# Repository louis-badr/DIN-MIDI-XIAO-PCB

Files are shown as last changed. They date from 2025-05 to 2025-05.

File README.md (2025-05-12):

# DIN-MIDI-XIAO-PCB

<div>
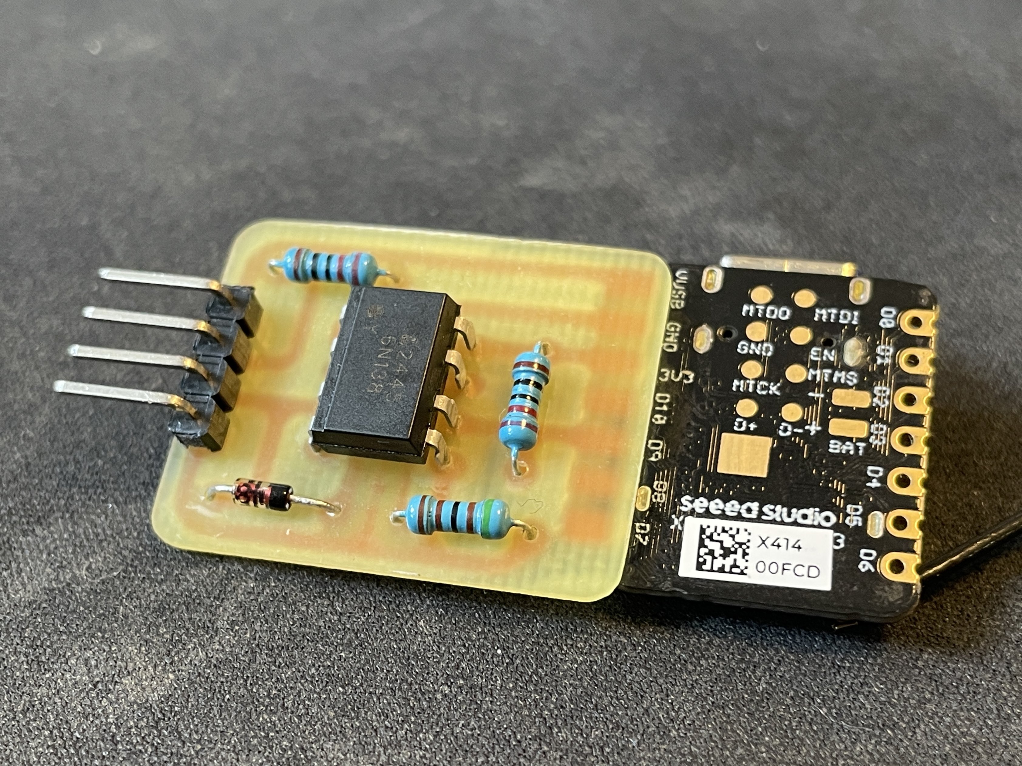
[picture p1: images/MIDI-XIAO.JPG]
    
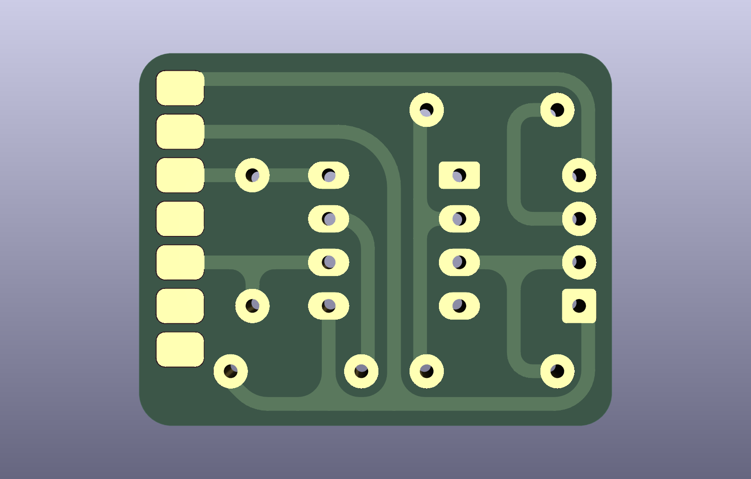
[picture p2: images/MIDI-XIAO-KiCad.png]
    
</div>

DIN MIDI PCB for Seeed Studio XIAO format boards - designed for CNC milling

Pinout:

-   Pin 1 -> GND
-   Pin 2 -> MIDI- / 5
-   Pin 3 -> MIDI+ / 4
-   Pin 4 -> +5V

Pin 1 and 4 are for powering the XIAO board, only connect them when USB is not.

```c++
#include <HardwareSerial.h>
#include <MIDI.h>

#define MIDI_IN 8 // pin 8 for XIAO ESP32S3 - change to your pin

MIDI_CREATE_INSTANCE(HardwareSerial, Serial1, MIDI)

void setup()
{
    Serial.begin(115200); // for debugging
    Serial1.begin(31250, SERIAL_8N1, MIDI_IN, -1); // for MIDI input
    MIDI.begin(MIDI_CHANNEL_OMNI);
}

void loop()
{
    MIDI.read();
}
```

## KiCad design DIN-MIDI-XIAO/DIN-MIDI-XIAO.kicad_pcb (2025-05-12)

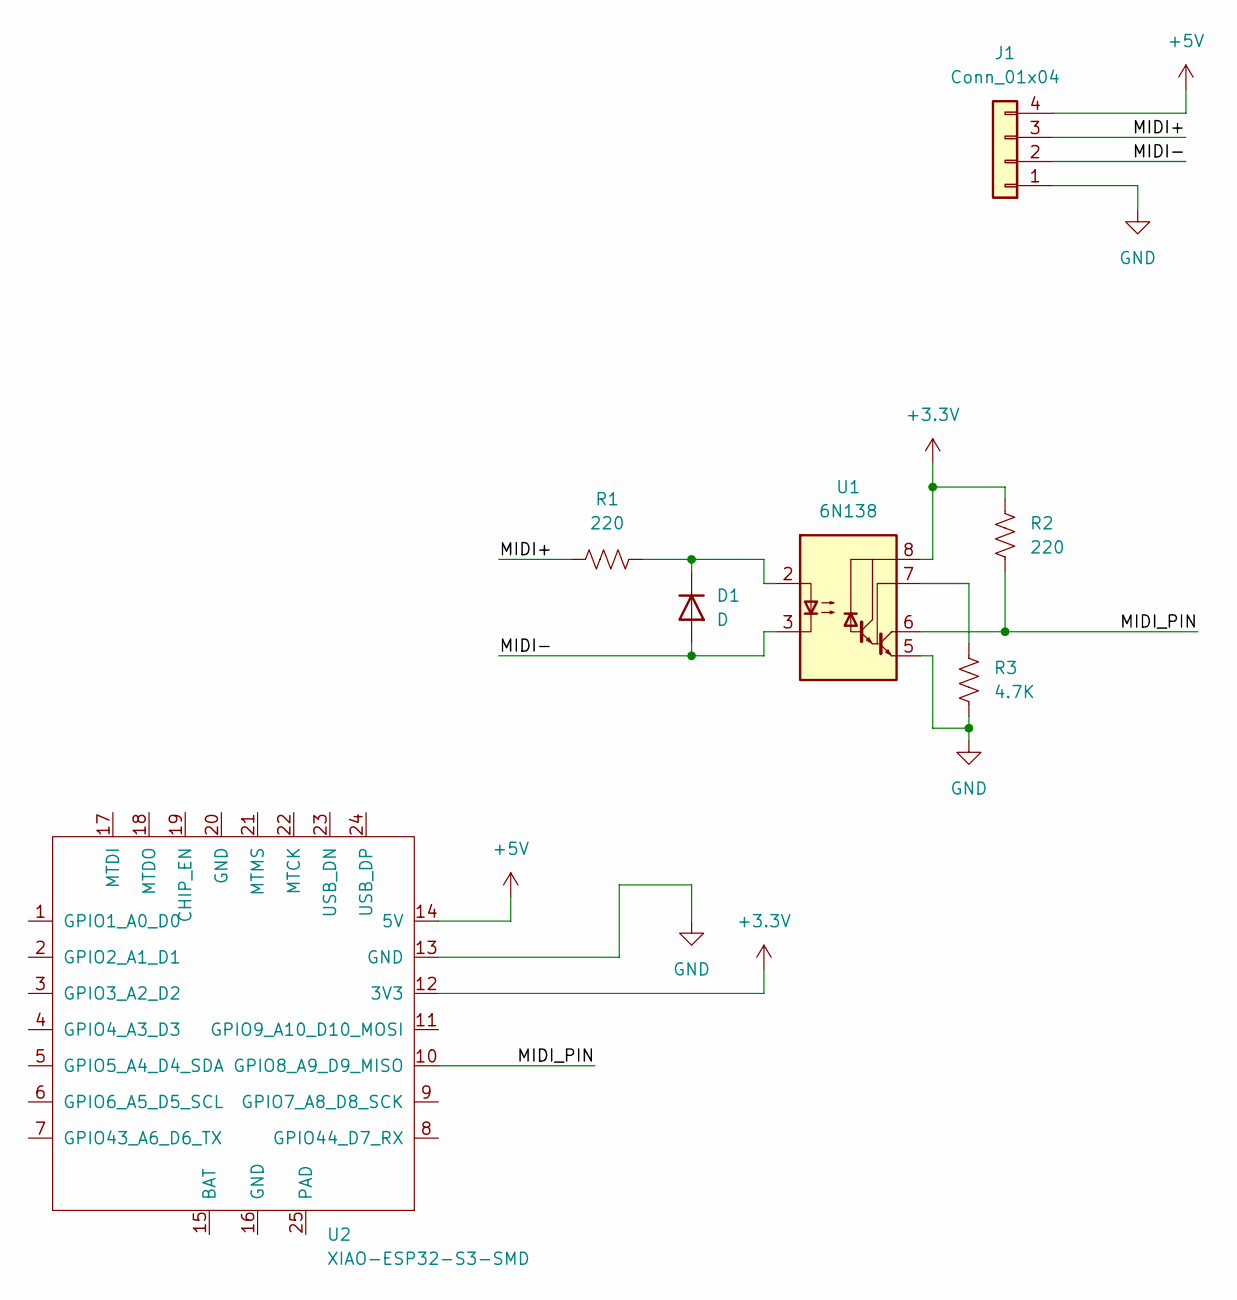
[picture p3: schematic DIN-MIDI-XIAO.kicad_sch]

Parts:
D1: D; R_Axial_DIN0207_L6.3mm_D2.5mm_P7.62mm_Horizontal
J1: Conn_01x04; PinHeader_1x04_P2.54mm_Horizontal
R1, R2: 220; R_Axial_DIN0207_L6.3mm_D2.5mm_P7.62mm_Horizontal
R3: 4.7K; R_Axial_DIN0207_L6.3mm_D2.5mm_P7.62mm_Horizontal
U1: 6N138; DIP-8_W7.62mm_Socket_LongPads
U2: XIAO-ESP32-S3-SMD; XIAO-ESP32S3-SMD

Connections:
+3.3V: R2.1, U1.8 (VCC), U2.12 (3V3)
+5V: J1.4, U2.14 (5V)
/MIDI+: J1.3, R1.1
/MIDI-: D1.2 (A), J1.2, U1.3 (C2)
/MIDI_PIN: R2.2, U1.6 (VO2), U2.10 (GPIO8_A9_D9_MISO)
GND: J1.1, R3.2, U1.5 (GND), U2.13 (GND)
unnamed: D1.1 (K), R1.2, U1.2 (C1)
unnamed: R3.1, U1.7 (VO1)

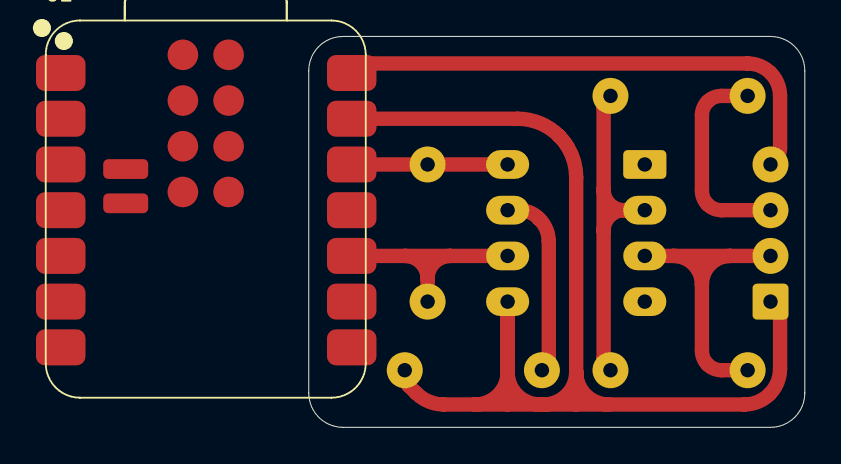
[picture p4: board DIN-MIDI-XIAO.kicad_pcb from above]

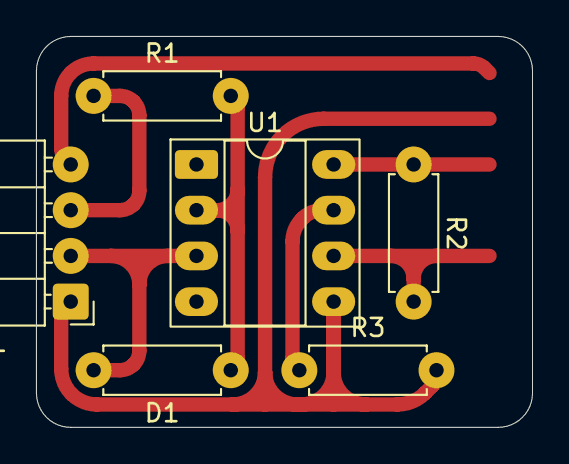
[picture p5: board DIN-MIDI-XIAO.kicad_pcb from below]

Board: 2 copper layers, 27.6 x 21.7 mm, 7 parts (6 on the bottom side), 8 nets.
